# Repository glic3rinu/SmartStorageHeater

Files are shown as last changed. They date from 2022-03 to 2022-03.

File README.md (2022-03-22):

# Smart Storage Heater

A stepper motor driven by an ESP8266 MCU to control the input load from old-style night saver storage heater, based on weather forecast.

Storage heaters are quite common in Ireland and the UK. They typically run during night hours when electricity is cheaper, storing heat on massive stones and releasing it during the day.

Such a system has a couple of disadvantages mitigated by this project:
1. One needs to anticipate weather conditions for next day in order to set the input load to an appropriate level.
2. Heater usually powers on at 11PM (when night saver shift starts), releasing wasted heat during the entire night, when everyone is asleep.

## Features

- OpenWeatherMap integration: uses temperature and sun forecast to determine the right input load for each night
- MQTT integration with Homeassistant
    - Alternative UDP protocol for status and override actions
- Optionally dismiss weather forecast and override the amount of hours powered on during the night (EEPROM persisted)
- RGB LED to indicate state:
    - Heater on: light blinking
    - Heater off: light solid
    - Override enabled: white light
    - No load input scheduled: green light
    - Low to moderate load input scheduled: blue light
    - Moderate to high load input scheduled: purple light
    - Error: red light

## BOM
- [28BYJ-48 stepper motor and stepper controller board](https://www.amazon.co.uk/HUABAN-28BYJ-48-Stepper-ULN2003-Driver/dp/B08B4J33HX)
- [NodeMcu Mini wireless D1 ESP8266 ESP-12F](https://www.amazon.co.uk/gp/product/B08QZ2887K)
- [Limit Switch, SPDT NO+NC Hinge Lever](https://www.amazon.co.uk/gp/product/B07YDFH7H3)
- [RGB LED diode Common Cathode](https://www.amazon.co.uk/Gaoominy-Common-Cathode-Emitting-Diodes/dp/B07R1HN9JW)
- USB cable

## Usage

```bash
nc -u 192.168.0.201 4210

mosquitto_sub -h 192.168.0.10 -p 1883 -t "homeassistant/#" -u $MQTT_USER -P $MQTT_PWD
mosquitto_sub -h 192.168.0.10 -p 1883 -t "home/#" -u $MQTT_USER -P $MQTT_PWD
```

## Pictures
<p align="center">
    <br>
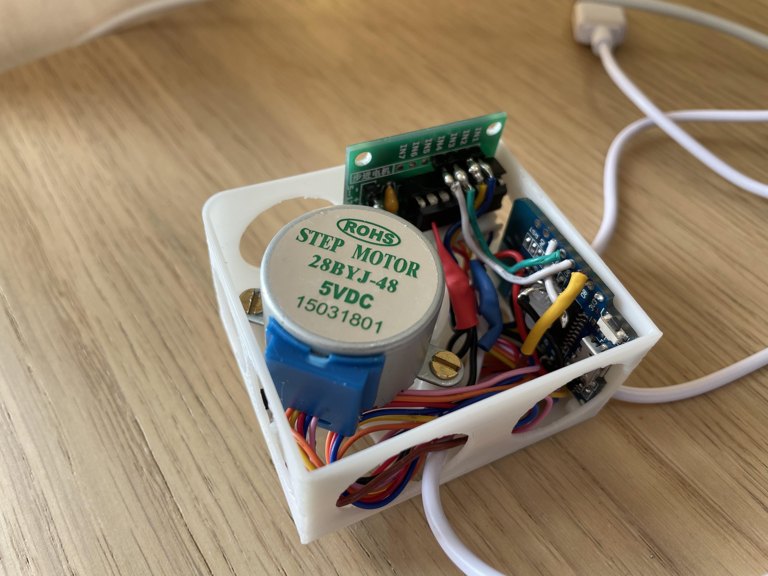
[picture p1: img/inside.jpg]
Inside
    
    <br>
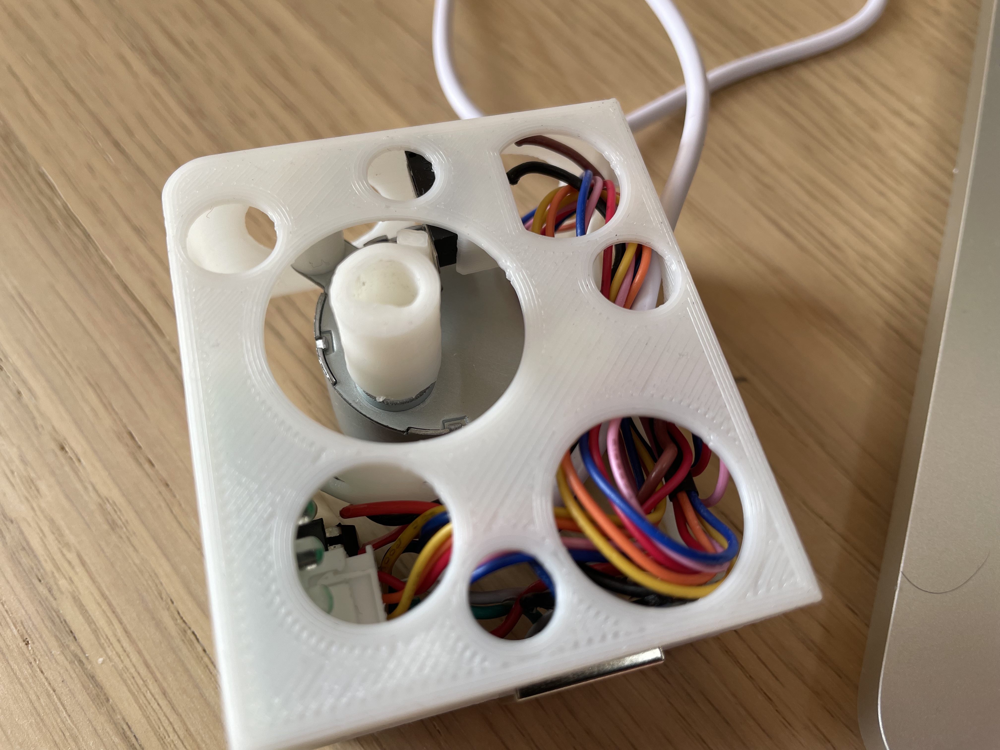
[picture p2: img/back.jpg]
Back
    
    <br>
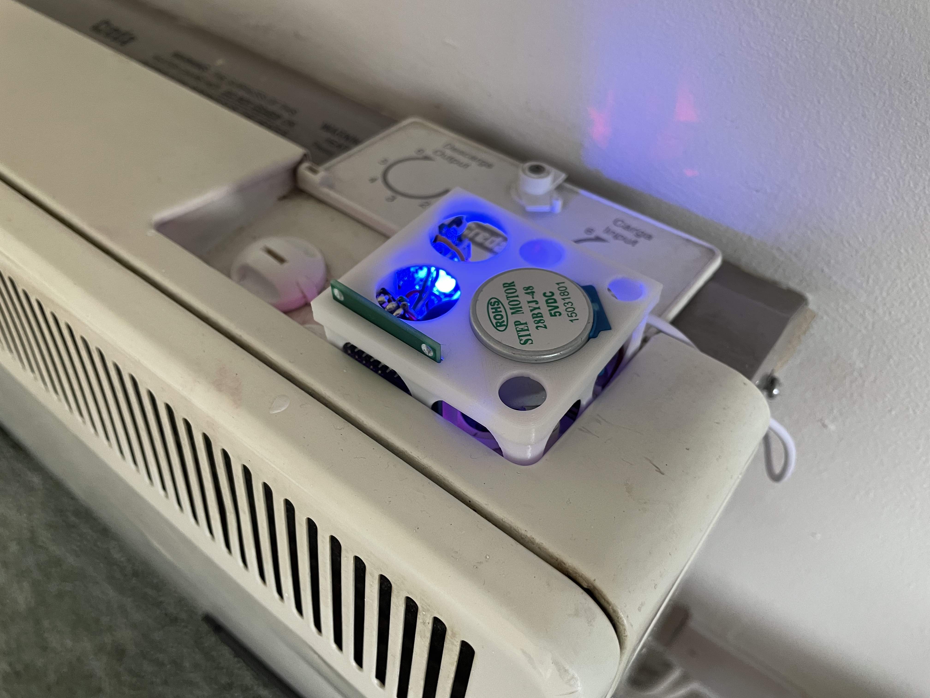
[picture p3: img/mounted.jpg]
Mounted
    
    <br>
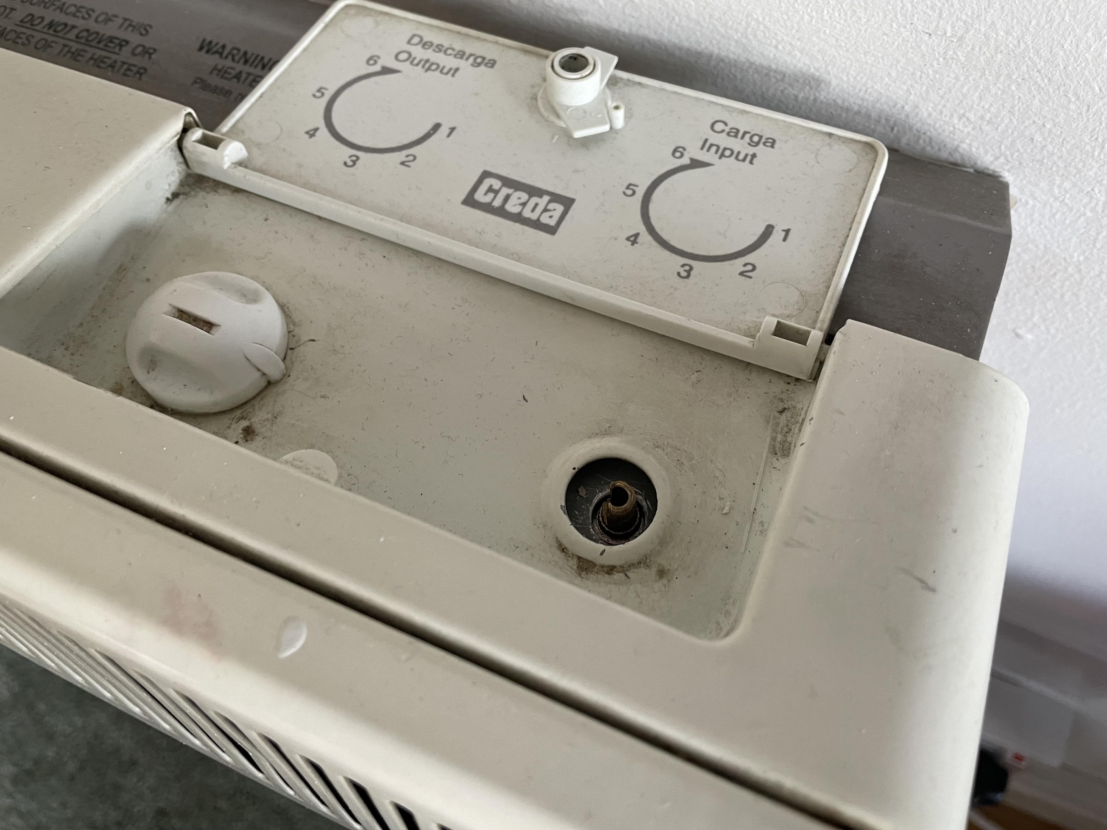
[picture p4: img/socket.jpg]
Socket
    
    <br>
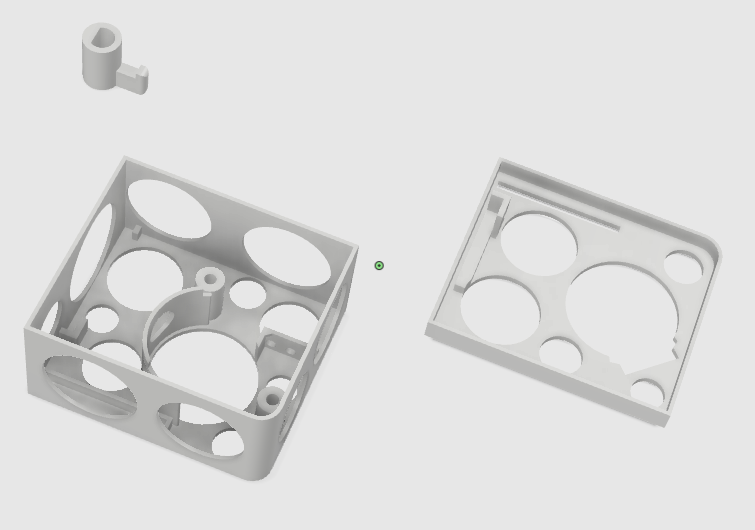
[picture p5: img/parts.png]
Rendered Parts
    
    <br>
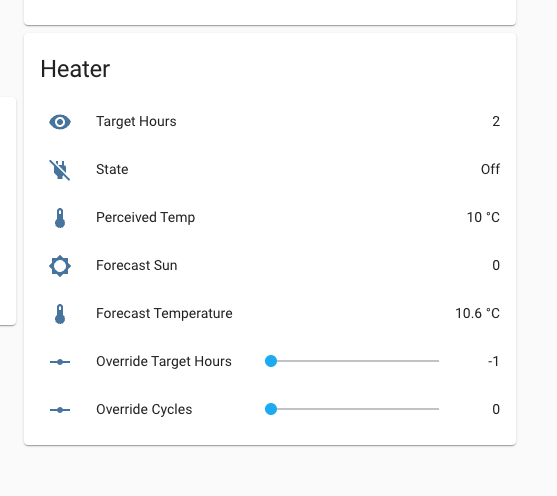
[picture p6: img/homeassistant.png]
Homeassistant
    
    <br>
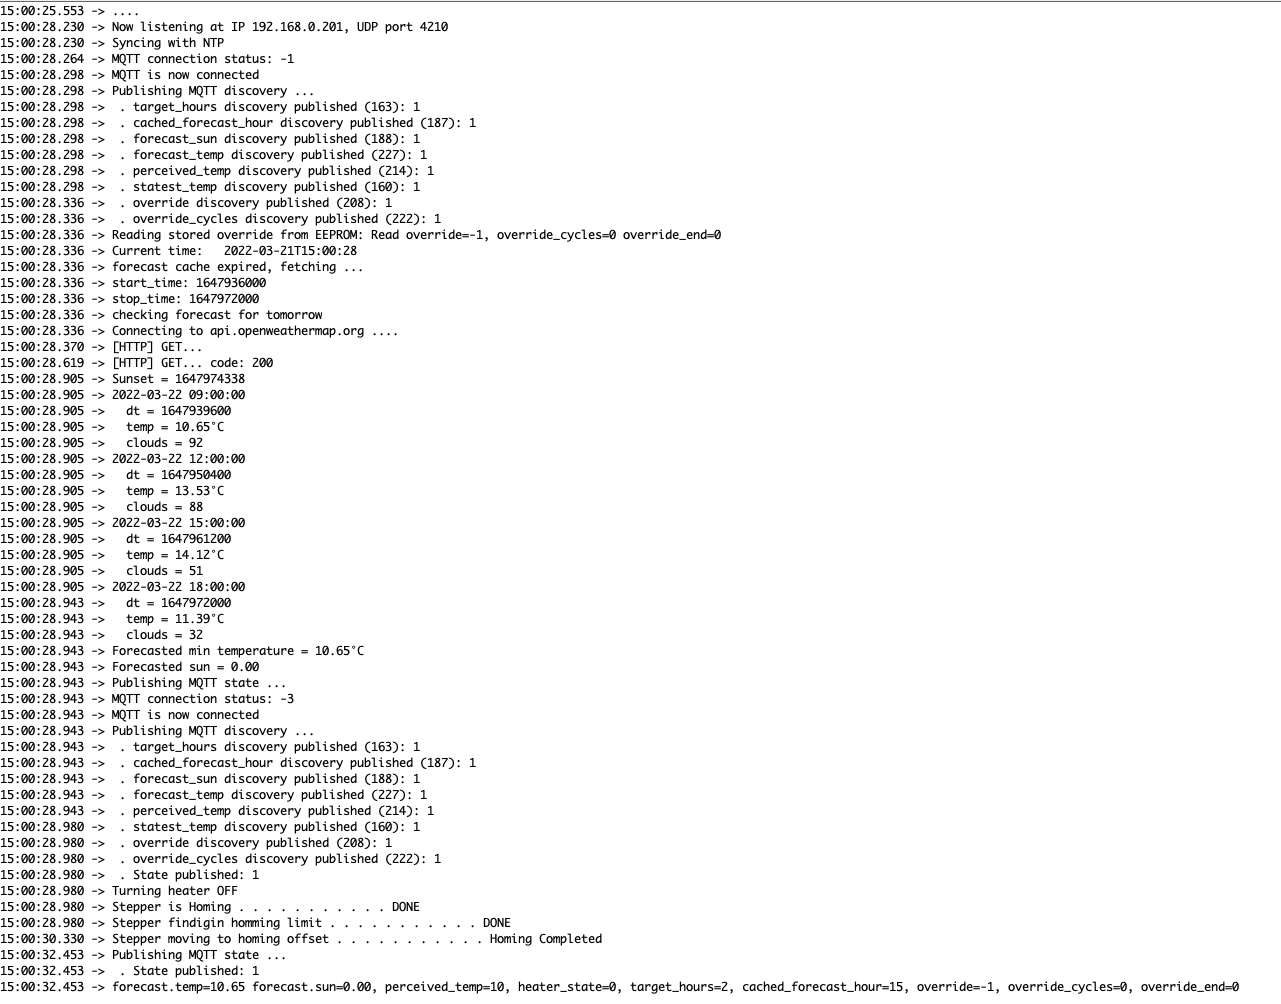
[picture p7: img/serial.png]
Serial Monitor
    
</p>

## License
```
           DO WHAT THE FUCK YOU WANT TO PUBLIC LICENSE
                   Version 2, December 2004
 
Copyright (C) 2022 Marc Aymerich

Everyone is permitted to copy and distribute verbatim or modified
copies of this license document, and changing it is allowed as long
as the name is changed.
 
           DO WHAT THE FUCK YOU WANT TO PUBLIC LICENSE
  TERMS AND CONDITIONS FOR COPYING, DISTRIBUTION AND MODIFICATION

 0. You just DO WHAT THE FUCK YOU WANT TO.
```

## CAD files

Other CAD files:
heater.f3d

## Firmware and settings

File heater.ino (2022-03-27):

#include <EEPROM.h>
#include <AccelStepper.h>
#include <WiFiUdp.h>
#include <ESP8266WiFi.h>
#include <ESP8266HTTPClient.h>
#include <ArduinoJson.h>
#include <NTPClient.h>
#include <TimeLib.h>
#include "RTClib.h"
#include <WiFiUdp.h>

// mgtt
#include <PubSubClient.h>

#include "secrets.h"

// https://diyi0t.com/segment-led-display-tutorial-for-arduino-and-esp8266/
// https://i2.wp.com/randomnerdtutorials.com/wp-content/uploads/2019/05/ESP8266-WeMos-D1-Mini-pinout-gpio-pin.png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
// https://codebender.cc/sketch:431066#home%20pin%20example%20using%20AccelStepper.ino


WiFiClient wifi;  // or WiFiClientSecure for HTTPS
const char* ssid = WIFI_SSID;
const char* password = WIFI_PASSWORD;
const char* device_name = "MainHeater";

short eeprom_magic_number = 20437;


// curl 'http://api.openweathermap.org/data/2.5/forecast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' | python -m json.tool
const char* openweathermap_url = "http://api.openweathermap.org/data/2.5/forecast?lat=" OPENWEATHERMAP_LAT "&units=metric&lon=" OPENWEATHERMAP_LON "&appid=" OPENWEATHERMAP_TOKEN;
HTTPClient http;

// https://roelofjanelsinga.com/articles/mqtt-discovery-with-an-arduino/
// https://pubsubclient.knolleary.net/
const char* mqtt_server = "192.168.0.10";
const int mqtt_port = 1883;
const char* mqtt_user = MQTT_USER;
const char* mqtt_password = MQTT_PASSWORD;
const char* state_topic = "home/heaters/main/state";
const char* set_override_topic = "home/heaters/main/set_override";
const char* set_override_cycles_topic = "home/heaters/main/set_override_cycles";
const char* set_led_topic = "home/heaters/main/set_led";
const char* availability_topic = "home/heaters/main/availability";

const char* mqtt_name = "Main Heater";

PubSubClient mqtt(wifi);

struct Forecast {
  float temp;
  float sun;
};

// hourly caching
Forecast cached_forecast = { -1, -1};
int cached_forecast_hour = -1;
// get min temp between these hours
int forecast_start_hour = 8;
int forecast_stop_hour = 18;

WiFiUDP Udp;
WiFiUDP ntpUdp;
IPAddress ip(192, 168, 0, 201);
IPAddress dns(192, 168, 0, 1);
IPAddress gateway(192, 168, 0, 1);
IPAddress subnet(255, 255, 255, 0);

unsigned int localUdpPort = 4210;  // local port to listen on
// https://www.ntppool.org/zone/europe
NTPClient ntp(ntpUdp, "ie.pool.ntp.org");

const int stop_hour = 8; // 24h hour when heater should be turned off
const int rows = 3;
const int columns = 2;
int temp_hours[ rows ][ columns ] = {
  // { temp, hours }
  { 15, 3 },
  { 10, 4 },
  { 5, 6 },
};
const int moderate_hours = 4;  // how many hours is considered a moderate use (>moderate: PURPLE else BLUE)
const float sun_temp_coeficient = 0.8;  // temp increase coeficient for every full hour of sun (adjust effective temperature based on heat from sun)

short heater_state = -1;  // -1: undefined, 0: off, 1: on
short override = -1;  // 1-: disabled, 0: heater off, else: number of target hours
long long override_end = 0; // 0: never stops, else: unix timestamp of last stop cycle
short led = 1;  // led light on/off

// ULN2003 Motor Driver Pins
#define IN1 5
#define IN2 4
#define IN3 14
#define IN4 12
#define HOMING_PIN 13
// initialize the stepper library
AccelStepper stepper(AccelStepper::HALF4WIRE, IN1, IN3, IN2, IN4);

#define RED 0
#define GREEN 15
#define BLUE 16


void heater_off() {
  Serial.println("Turning heater OFF");
  long initial_homing = -1;
  // set the speed and acceleration
  //  Set Max Speed and Acceleration of each Steppers at startup for homing
  stepper.setMaxSpeed(100.0);      // Set Max Speed of Stepper (Slower to get better accuracy)
  stepper.setAcceleration(100.0);  // Set Acceleration of Stepper

  // set target position
  Serial.print("Stepper is Homing . . . . . . . . . . . ");
  while (digitalRead(HOMING_PIN) == HIGH) {
    stepper.moveTo(initial_homing);  // Set the position to move to
    initial_homing--;  // Decrease by 1 for next move if needed
    stepper.run();  // Start moving the stepper
    do_concurrent_tasks();
    delay(5);
  }
  Serial.print("DONE\r\nStepper findigin homming limit . . . . . . . . . . . ");
  stepper.setCurrentPosition(0);  // Set the current position as zero for now
  initial_homing = 1;
  while (digitalRead(HOMING_PIN) == LOW) { // Make the Stepper move CW until the switch is deactivated
    stepper.moveTo(initial_homing);
    stepper.run();
    initial_homing++;
    do_concurrent_tasks();
    delay(5);
  }
  Serial.print("DONE\r\nStepper moving to homing offset . . . . . . . . . . . ");
  // offset some steps to make sure heater is in a closed position
  stepper.setCurrentPosition(0);
  stepper.moveTo(-120);
  while (stepper.distanceToGo()) {
    stepper.run();
    do_concurrent_tasks();
  }
  stepper.setCurrentPosition(0);
  heater_state = 0;
  Serial.println("Homing Completed");
}

void heater_on() {
  Serial.println("Turning heater ON");
  if (heater_state == -1) {
    Serial.println(" . Stepper needs homming:");
    heater_off();
  } else if (heater_state == 1) {
    Serial.println("WARNING: heater already ON");
  }
  stepper.moveTo(3 * 1024 - 100);
  while (stepper.distanceToGo()) {
    stepper.run();
    do_concurrent_tasks();
  }
  heater_state = 1;
  Serial.println("Heater ON completed");
}


Forecast get_forecast(DateTime now) {
  if (cached_forecast_hour != now.hour() || cached_forecast.temp == -1) {
    Serial.println("forecast cache expired, fetching ...");
    // keep clock in sync
    ntp.update();
    Forecast forecast = fetch_forecast(now);
    if (forecast.temp == -1) {
      // error fetching temp
      return { -1, -1};
    }
    cached_forecast = forecast;
    cached_forecast_hour = now.hour();
    publish_mqtt_state(forecast);
  }
  return cached_forecast;
}


Forecast fetch_forecast(DateTime now) {
  float temp_avg = -1;
  float sun = -1;
  int sunset = 0;
  int count = 0;

  if (WiFi.status() != WL_CONNECTED) {
    if (reconnect_wifi() == -1) {
      return { -1, -1};
    }
  }

  // cast to long instead of time_t because - operations with unsigned lead to unexpected values
  long long next_stop;
  get_next_stop_time(now, &next_stop);
  long long start_time = next_stop + ((forecast_start_hour - stop_hour) * 60 * 60);
  long long stop_time = next_stop + ((forecast_stop_hour - stop_hour) * 60 * 60);
  Serial.print("start_time: ");
  Serial.println(start_time);
  Serial.print("stop_time: ");
  Serial.println(stop_time);

  if (((DateTime) next_stop).day() != now.day()) {
    Serial.println("checking forecast for tomorrow");
    sunset += 24 * 60 * 60;
  }

  Serial.println("Connecting to api.openweathermap.org ....");
  int err = 0;
  http.useHTTP10(true);
  if (http.begin(wifi, openweathermap_url)) {
    Serial.print("[HTTP] GET...\n");
    int httpCode = http.GET();
    if (httpCode > 0) {
      Serial.printf("[HTTP] GET... code: %d\n", httpCode);
      if (httpCode == HTTP_CODE_OK || httpCode == HTTP_CODE_MOVED_PERMANENTLY) {
        DynamicJsonDocument doc(24576);
        DeserializationError error = deserializeJson(doc, http.getStream());
        if (error) {
          Serial.print("Deserialization failed with code: ");
          Serial.println(error.c_str());
        } else {
          JsonArray list = doc["list"].as<JsonArray>();
          float temp;
          long long dt;
          int clouds;
          sunset += (long long)doc["city"]["sunset"];
          sun = 0.0;
          Serial.printf("Sunset = %d\r\n", sunset);
          for (JsonVariant item : list) {
            temp = (float)(item["main"]["temp"]);
            dt = (long long)(item["dt"]);
            if (start_time <= dt && stop_time >= dt) {
              ++count;
              clouds = (int)item["clouds"]["all"];
              Serial.println((const char*)item["dt_txt"]);
              Serial.printf("  dt = %d\r\n", dt);
              Serial.printf("  temp = %.2f°C\r\n", temp);
              if (temp_avg == -1)
                temp_avg = temp;
              else
                temp_avg += temp;
              if (sunset > dt) {
                Serial.printf("  clouds = %d\r\n", clouds);
                if (clouds < 2)
                  sun += 3.0;
                else if (clouds < 10)
                  sun += 2.0;
                else if (clouds < 20)
                  sun += 1.5;
                else if (clouds < 30)
                  sun += 1.0;
              }
            }
          }
        }
        if (count) {
          temp_avg = temp_avg / count;
        }
        Serial.printf("Forecasted avg temperature = %.2f°C\r\n", temp_avg);
        Serial.printf("Forecasted sun = %.2f\r\n", sun);
      }
    } else {
      Serial.printf("[HTTP] GET failed, error: %s\n", http.errorToString(httpCode).c_str());
    }
    http.end();
  } else {
    Serial.printf("[HTTP} Unable to connect\n");
  }
  return {temp_avg, sun};
}


int get_override_cycles() {
  DateTime now = ntp.getEpochTime();
  if (override_end == 0) {
    return 0;
  } else if (now > override_end) {
    Serial.println("ERROR: override_end can't be negative");
    return 0;
  } else {
    // number of cycles left
    return ceil((float)(override_end - (long long)now.unixtime()) / (24 * 60 * 60));
  }
}


void get_state(char *state, Forecast forecast) {
  int target_hours = get_target_hours(forecast);
  sprintf(state, "forecast.temp=%.2f forecast.sun=%.2f, perceived_temp=%d, heater_state=%d, target_hours=%d, cached_forecast_hour=%d, override=%d, override_cycles=%d, override_end=%d, led=%d\r\n",
          forecast.temp,
          forecast.sun,
          get_perceived_temp(forecast),
          heater_state,
          target_hours,
          cached_forecast_hour,
          override,
          get_override_cycles(),
          override_end,
          led
         );
}


int get_perceived_temp(Forecast forecast) {
  return forecast.temp + sun_temp_coeficient * forecast.sun;
}


int get_target_hours(Forecast forecast) {
  int target_hours = 0;
  int perceived_temp = get_perceived_temp(forecast);
  for ( int i = 0; i < rows; ++i ) {
    if (perceived_temp < temp_hours[i][0]) {
      target_hours = temp_hours[i][1];
    }
  }
  return target_hours;
}


void read_udp_cmd() {
  char payload[255];  // buffer for incoming packets
  char *cmd;
  int steps;

  // receive incoming UDP packets
  int len = Udp.read(payload, 255);
  if (len > 0) {
    payload[len ] = 0;
  }
  Serial.printf("UDP packet contents: %s\n", payload);
  char *buffer = strdup(payload);

  Udp.beginPacket(Udp.remoteIP(), Udp.remotePort());
  cmd = strsep(&buffer, ":");
  if ( cmd == NULL ) {
    Udp.write("INVALID FORMAT: expected cmd");
  } else {
    Serial.printf("  - Command: '%s'\n", cmd);
    if (strcmp(cmd, "status") == 0) {
      char state[255];
      get_state(state, cached_forecast);
      Udp.write(state);
    } else if ( strcmp(cmd, "set_override") == 0) {
      short override_value = atoi(strsep(&buffer, ":"));
      if (override_value == NULL) {
        Udp.write("set_override has invalid override value");
      } else {
        set_override(override_value);
        Udp.write("set_override ACK\r\n");
      }
    } else if ( strcmp(cmd, "set_override_cycles") == 0) {
      int override_cycles = atoi(strsep(&buffer, ":"));
      if ((override_cycles == NULL) || (override_cycles < 0)) {
        Udp.write("override_cycles has invalid override value");
      } else {
        set_override_cycles(override_cycles);
        Udp.write("set_override_cycles ACK\r\n");
      }
    } else if ( strcmp(cmd, "set_led") == 0) {
      short led_value = atoi(strsep(&buffer, ":"));
      if (led_value != 1 && led_value != 0) {
        Udp.write("set_led has invalid override value");
      } else {
        set_led(led_value);
        Udp.write("set_led ACK\r\n");
      }
    } else {
      Udp.write("Unkown command\r\n");
    }
  }
  Udp.endPacket();
}


void do_concurrent_tasks() {
  // stuff to do when moving stepper or blinking lights
  mqtt.loop();
  if (Udp.parsePacket()) {
    Serial.printf("Received packet from %s, port %d\n", Udp.remoteIP().toString().c_str(), Udp.remotePort());
    read_udp_cmd();
  }
  yield();
}


void set_override_cycles(int value) {
  Serial.printf("set_override_cycles(%d): ", value);
  if (value > 0) {
    DateTime now = ntp.getEpochTime();
    time_t stop_time;
    get_next_stop_time(now, &stop_time);
    --value;
    override_end = stop_time + (value * 24 * 60 * 60);
  } else if (value < 0) {
    Serial.printf("ERROR negative set_override_cycles not allowed");
    return;
  } else {
    override_end = 0;
  }
  int addr = 4;
  EEPROM.write(addr, (override_end >> 56) & 0xFF);
  EEPROM.write(addr + 1, (override_end >> 48) & 0xFF);
  EEPROM.write(addr + 2, (override_end >> 40) & 0xFF);
  EEPROM.write(addr + 3, (override_end >> 32) & 0xFF);
  EEPROM.write(addr + 4, (override_end >> 24) & 0xFF);
  EEPROM.write(addr + 5, (override_end >> 16) & 0xFF);
  EEPROM.write(addr + 6, (override_end >> 8) & 0xFF);
  EEPROM.write(addr + 7, override_end & 0xFF);
  if (EEPROM.commit()) {
    Serial.println("EEPROM set_override_cycles successfully committed");
  } else {
    Serial.println("ERROR! set_override_cycles EEPROM commit failed");
  }
  publish_mqtt_state(cached_forecast);
}


void set_override(short value) {
  Serial.printf("set_override(%d): ", value);
  if (value > 24 || value < -1) {
    Serial.println("ERROR: Invalid ser_override value");
    return;
  }
  override = value;
  // ESP 2 byte shorts
  int addr = 2;
  EEPROM.write(addr, override >> 8);
  EEPROM.write(addr + 1, override & 0xFF);
  if (EEPROM.commit()) {
    Serial.println("EEPROM set_override successfully committed");
  } else {
    Serial.println("ERROR! set_override EEPROM commit failed");
  }
  publish_mqtt_state(cached_forecast);
}


void set_led(short value) {
  Serial.printf("set_led(%d): ", value);
  if (value != 0 && value != 1) {
    Serial.println("ERROR: Invalid set_led value");
    return;
  }
  led = value;
  // ESP 2 byte shorts
  int addr = 12;
  EEPROM.write(addr, led >> 8);
  EEPROM.write(addr + 1, led & 0xFF);
  if (EEPROM.commit()) {
    Serial.println("EEPROM set_led successfully committed");
  } else {
    Serial.println("ERROR! set_led EEPROM commit failed");
  }
  publish_mqtt_state(cached_forecast);
}

void mqtt_callback(char* topic, byte * payload, unsigned int length) {
  payload[length] = NULL;
  Serial.printf("Message arrived [%s] '%s'\n", topic, (char*)payload);

  if (strcmp(topic, set_override_topic) == 0) {
    set_override(atoi((char*)payload));
  } else if (strcmp(topic, set_override_cycles_topic) == 0) {
    set_override_cycles(atoi((char*)payload));
  } else if (strcmp(topic, set_led_topic) == 0) {
    if (strcmp((char*)payload, "ON") == 0) {
      set_led(1);
    } else {
      set_led(0);
    }
  } else {
    Serial.println("Unknown topic");
  }
}

void send_mqtt_discovery_messages() {
  Serial.println("Publishing MQTT discovery ...");

  DynamicJsonDocument doc(1024);
  char buffer[512];
  size_t n;
  bool published;

  doc["stat_t"] = state_topic;
  doc["frc_upd"] = true;
  doc["avty_t"] = availability_topic;

  JsonObject dev  = doc.createNestedObject("dev");
  dev["name"] = "Main Heater"; 
  JsonArray dev_identifiers = dev.createNestedArray("identifiers");
  dev_identifiers.add("main_heater");

  doc["name"] = "Target Hours";
  doc["val_tpl"] = "{{ value_json.target_hours|default(0) }}";
  doc["uniq_id"] = "main_heater-target_hours";
  n = serializeJson(doc, buffer);
  published = mqtt.publish("homeassistant/sensor/main_heater/target_hours/config", buffer, n);
  Serial.printf(" . target_hours discovery published (%d): %d\r\n", n, published);

  doc["name"] = "Cached Forecast Hour";
  doc["val_tpl"] = "{{ value_json.cached_forecast_hour|default(0) }}";
  doc["uniq_id"] = "main_heater-cached_forecast_hour";
  n = serializeJson(doc, buffer);
  published = mqtt.publish("homeassistant/sensor/main_heater/cached_forecast_hour/config", buffer, n);
  Serial.printf(" . cached_forecast_hour discovery published (%d): %d\r\n", n, published);

  doc["name"] = "Forecast Sun";
  doc["dev_cla"] = "illuminance";
  doc["val_tpl"] = "{{ value_json.forecast_sun|default(0) }}";
  doc["uniq_id"] = "main_heater-perceived_sun";
  n = serializeJson(doc, buffer);
  published = mqtt.publish("homeassistant/sensor/main_heater/forecast_sun/config", buffer, n);
  Serial.printf(" . forecast_sun discovery published (%d): %d\r\n", n, published);

  doc["name"] = "Forecast Temperature";
  doc["unit_of_meas"] = "°C";
  doc["dev_cla"] = "temperature";
  doc["val_tpl"] = "{{ value_json.forecast_temp|default(0)|round(1) }}";
  doc["uniq_id"] = "main_heater-forecast_temp";
  n = serializeJson(doc, buffer);
  published = mqtt.publish("homeassistant/sensor/main_heater/forecast_temp/config", buffer, n);
  Serial.printf(" . forecast_temp discovery published (%d): %d\r\n", n, published);

  doc["name"] = "Perceived Temp";
  doc["unit_of_meas"] = "°C";
  doc["dev_cla"] = "temperature";
  doc["val_tpl"] = "{{ value_json.perceived_temp|default(0) }}";
  doc["uniq_id"] = "main_heater-perceived_temp";
  n = serializeJson(doc, buffer);
  published = mqtt.publish("homeassistant/sensor/main_heater/perceived_temp/config", buffer, n);
  Serial.printf(" . perceived_temp discovery published (%d): %d\r\n", n, published);

  doc.remove("unit_of_meas");
  doc.remove("dev_cla");

  doc["name"] = "State";
  doc["dev_cla"] = "power";
  doc["val_tpl"] = "{{ value_json.state|default(0) }}";
  doc["uniq_id"] = "main_heater-state";
  n = serializeJson(doc, buffer);
  published = mqtt.publish("homeassistant/binary_sensor/main_heater/state/config", buffer, n);
  Serial.printf(" . statest_temp discovery published (%d): %d\r\n", n, published);

  doc.remove("dev_cla");
  doc.remove("frc_upd");

  doc["name"] = "LED";
  doc["val_tpl"] = "{{ value_json.led|default(0) }}";
  doc["uniq_id"] = "main_heater-led";
  doc["cmd_t"] = set_led_topic;
  n = serializeJson(doc, buffer);
  published = mqtt.publish("homeassistant/switch/main_heater/led/config", buffer, n);
  Serial.printf(" . led discovery published (%d): %d\r\n", n, published);

  doc["name"] = "Override Target Hours";
  doc["val_tpl"] = "{{ value_json.override|default(0) }}";
  doc["uniq_id"] = "main_heater-override";
  doc["min"] = -1;
  doc["max"] = 24;
  doc["cmd_t"] = set_override_topic;
  n = serializeJson(doc, buffer);
  published = mqtt.publish("homeassistant/number/main_heater/override/config", buffer, n);
  Serial.printf(" . override discovery published (%d): %d\r\n", n, published);

  doc["name"] = "Override Cycles";
  doc["val_tpl"] = "{{ value_json.override_cycles|default(0) }}";
  doc["uniq_id"] = "main_heater-override_cycles";
  doc["min"] = 0;
  doc["max"] = 30;
  doc["cmd_t"] = set_override_cycles_topic;
  n = serializeJson(doc, buffer);
  published = mqtt.publish("homeassistant/number/main_heater/override_cycles/config", buffer, n);
  Serial.printf(" . override_cycles discovery published (%d): %d\r\n", n, published);
}


int reconnect_wifi() {
  Serial.println("Reconnecting to WiFi...");
  WiFi.disconnect();
  WiFi.reconnect();
  for (int i = 0; i < 70; ++i) {
    if (WiFi.status() == WL_CONNECTED) {
      Serial.println("");
      return 0;
    }
    Serial.print("_");
    delay(500);
  }
  Serial.println("ERROR connecting to wifi");
  return -1;
}
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
void loop() {
  DateTime now = ntp.getEpochTime();
  Serial.println(String("Current time:\t") + now.timestamp(DateTime::TIMESTAMP_FULL));
  Forecast forecast = get_forecast(now);
  int target_hours = get_target_hours(forecast);
  int effective_target_hours = target_hours;
  long long stop_time;
  get_next_stop_time(now, &stop_time);

  // apply override
  if (override != -1) {
    if ((override_end == 0) || (now < override_end)) {
      effective_target_hours = override;
    } else if (override_end > 0 && now > override_end) {
      set_override(-1);
      set_override_cycles(0);
    }
  }

  // set heater state
  if ( ((stop_time - (effective_target_hours * 60 * 60)) < now.unixtime()) && (now.unixtime() < stop_time) ) {
    if (heater_state != 1)
      heater_on();
  } else if (heater_state != 0) {
    heater_off();
  }

  publish_mqtt_state(forecast);
  char state[255];
  get_state(state, forecast);
  Serial.print(state);
  // sleep for 1 minute but maybe blink LED
  for (int i = 0; i < 2 * 60; ++i) {
    if (led == 1) {
      if (override != -1) {
        digitalWrite(RED, HIGH);
        digitalWrite(GREEN, HIGH);
        digitalWrite(BLUE, HIGH);
      } else if (forecast.temp == -1 || heater_state == -1) {
        digitalWrite(RED, HIGH);
        digitalWrite(GREEN, LOW);
        digitalWrite(BLUE, LOW);
      } else if (target_hours > moderate_hours) {
        digitalWrite(RED, HIGH);
        digitalWrite(GREEN, LOW);
        digitalWrite(BLUE, HIGH);
      } else if (target_hours > 0) {
        digitalWrite(RED, LOW);
        digitalWrite(GREEN, LOW);
        digitalWrite(BLUE, HIGH);
      } else {
        digitalWrite(RED, LOW);
        digitalWrite(GREEN, HIGH);
        digitalWrite(BLUE, LOW);
      }
      if (heater_state == 1 && i % 2) {
        //blink
        digitalWrite(RED, LOW);
        digitalWrite(GREEN, LOW);
        digitalWrite(BLUE, LOW);
      }
    } else {
      digitalWrite(RED, LOW);
      digitalWrite(GREEN, LOW);
      digitalWrite(BLUE, LOW);
    }
    do_concurrent_tasks();
    delay(500);
  }
  if (led == 1) {
    // looping colors
    digitalWrite(RED, HIGH);
    digitalWrite(GREEN, HIGH);
    digitalWrite(BLUE, LOW);
  }
}

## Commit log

2022-03-21 added socket image
2022-03-22 added support for turning off status led
2022-03-27 Add basic support for HA device
